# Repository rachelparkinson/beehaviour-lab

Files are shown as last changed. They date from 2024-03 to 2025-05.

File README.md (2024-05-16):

# Beehaviour Lab Project

## Description
This is the project file for the Beehaviour Lab

## Contents
aparatus_templates --> dxf files for laser cutting the Beehaviour Lab stand and cages

rPi_program --> Raspberry Pi program for controlling Beehaviour Lab and recording data

vid_audio_processing --> code for adjusting frame rate of video and combining video and audio files

database --> code for scraping experiment data from .json metadata files and filing in MongoDB

## Contributors
All design & code written by Rachel Parkinson, laser cutting files produced by Jennifer Scott.

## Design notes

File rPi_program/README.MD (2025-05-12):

# Beehaviour Lab Raspberry Pi Program

## Description
Program to control rPi and components of Beehaviour Lab. 

## Installation
All files can be transferred to an rPi Model 4B to control: rPi NoIR camera (V2), Røde SmartLav+ lapel microphone, DHT22 temperature and humidity probe, LED lighting panels, time clapper (buzzer + LEDs), and OLED display screen.

## Usage
Update config.json with experiment-specific information, including recording segment length and number of replicates.

Run program from "main.py" file. 

## Requirements

Use a setup rPi to download all requirements, and then transfer to the other rPis using VNC. 

## 1. on the Internet-connected rPi:

```
#!/bin/bash

# Create directories
mkdir -p rpi_packages/apt
mkdir -p rpi_packages/pip

# Download apt packages and dependencies
cd rpi_packages/apt
apt-get download \
    python3-opencv \
    opencv-data \
    ffmpeg \
    i2c-tools \
    python3-smbus \
    alsa-utils \
    $(apt-cache depends python3-opencv opencv-data ffmpeg i2c-tools python3-smbus alsa-utils | grep -E 'Depends|Recommends|Suggests' | cut -d: -f2 | tr -d '<>' | sed '/^$/d')

# Download pip packages
cd ../pip
pip3 download \
    opencv-python \
    picamera2 \
    tflite-runtime \
    adafruit-circuitpython-ssd1306 \
    RPi.GPIO \
    board \
    busio \
    adafruit-blinka

# Create tar archive
cd ../..
tar -czvf rpi_packages.tar.gz rpi_packages/
```

## 2. on the other rPis:

```
#!/bin/bash

# Extract the archive
tar -xzvf rpi_packages.tar.gz

# Install apt packages
cd rpi_packages/apt
sudo dpkg -i *.deb

# Handle any dependency issues
sudo apt --fix-broken install

# Install pip packages
cd ../pip
pip3 install --no-index --find-links . *.whl
```

## 3. enable I2C on each rPi for the OLED display

```
sudo raspi-config
# Navigate to Interfacing Options > I2C > Enable
```

## 4. For audio recording, set the USB mic as the default audio input

```
sudo nano /etc/asound.conf
# Add the following lines to the file:
   pcm.!default {
       type plug
       slave.pcm "plughw:1,0"  # Adjust card,device numbers as needed
   }
```

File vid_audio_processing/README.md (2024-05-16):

# Video and audio file procesing

## Description
Programme for adjusting the frame duration on videos and aligning with audio recordings plus offset. 

## Files
resample_framerate.py --> recalculates the framerate of the video file knowing the number of frames (taken from the video_metadata file) and expected duration (5 minutes).

combine_vid_aud.py --> merge the separate audio and video files.

clip_media.py --> quick script to trim  files (i.e., extract segment from video)

## To do:
Need to check: is number of frames accurately represented in video_metadata.json files? If so, use this instead of querying as it takes forever.

Also: how accurate is the 0.01s time offset?

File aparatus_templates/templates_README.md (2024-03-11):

# Template files

Files are for laser cutting the Beehaviour Lab stand and cages. Stand printed in 5 mm perspex, and boxes may be printed in 3 or 5 mm clear perspex.

# Assembly

Stands are assembled with the use of M3 screws. Cages are assembled using Tensol acrylic glue. Components are affixed to stands using M2 screws.

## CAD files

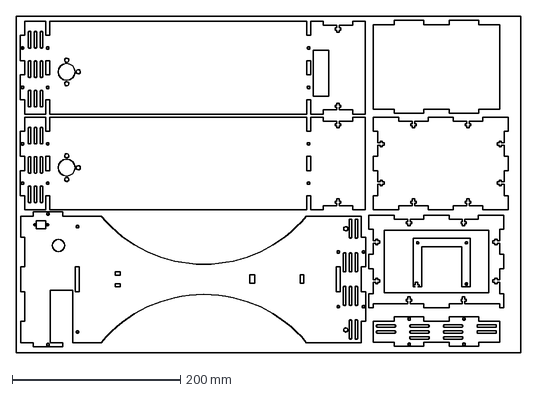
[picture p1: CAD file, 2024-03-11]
aparatus_templates/White_Bulk_Sheet1.dxf
600.0 x 400.0 mm

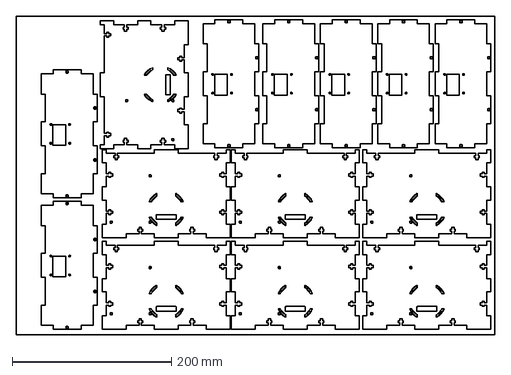
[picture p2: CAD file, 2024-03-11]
aparatus_templates/White_Bulk_Sheet2.dxf
600.0 x 400.0 mm

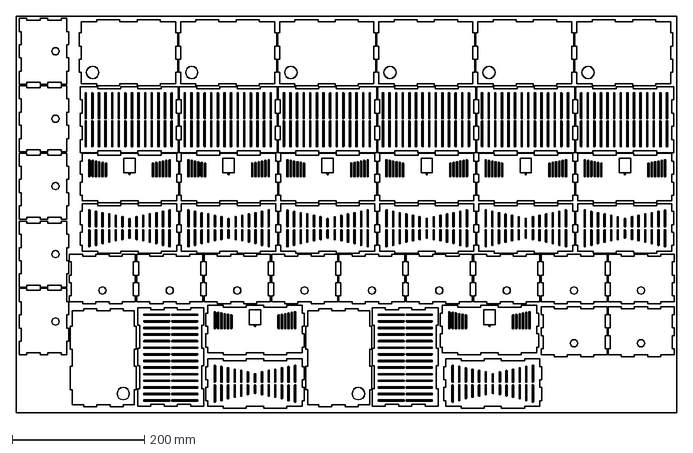
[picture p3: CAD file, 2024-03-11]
aparatus_templates/3mmBox.dxf
1000.0 x 600.0 mm

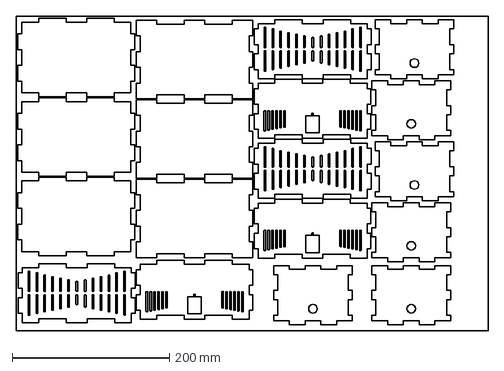
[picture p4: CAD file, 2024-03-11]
aparatus_templates/5mmBox.dxf
600.0 x 400.0 mm

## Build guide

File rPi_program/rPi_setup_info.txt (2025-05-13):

## NEW VERSION - rPi SETUP for BEEhaviour Lab ##

## ---------------------- ##

Start with:
- SD card (using 128 GB)
- Raspberry Pi 4B (4 GB)
- USB-SATA cable
- PiCam (using NoIR V2)
- SSD (Gigastone Game Pro SSD 512 GB)

## ---------------------- ##

1. Flash card
- Download / open Raspberry Pi Imager (at least v1.7)
- Select Raspbian version:
  - Old setup uses DEBIAN-BULLSEYE (newest release isn't working with VNC as of 14/10/2023)
  - New setup uses DEBIAN-BOOKWORM 12
- Select SD card from storage option
- Click “Settings” and enable:
  - Enable SSH
  - Set username and password (e.g., username: rPi1, password: pipass)

## ---------------------- ##

2. Connect to monitor, mouse, keyboard
- Make sure Pi is powered off before inserting SD card
- Insert SD, plug it in

## ---------------------- ##

4. rPi configuration

# Download setup file from GitHub:
wget https://github.com/rachelparkinson/beehaviour-lab/archive/refs/heads/main.zip

# Unzip and run:
unzip main.zip
cd beehaviour-lab-main/rPi_program
chmod +x setup_rpi.sh
./setup_rpi.sh

## ---------------------- ##

5. Log in to RealVNC to allow for file transfer
sudo vnclicensewiz

## ---------------------- ##

6. Transfer git program (from local copy via ssh)

# Fix rPi name (e.g., rPi1...) and replace <raspberry_pi_ip> with actual IP. 
# Need to be on same wifi network as rPi for this to work

scp -r /Users/user/Documents/beehaviour-lab/rPi_program rPi21@<raspberry_pi_ip>:/home/rPi21/

## ----------------------- ## 

8. Setup SSD

Connect SSD
- Connect to USB 3.0 (blue)
- wait 30s, then in Gparted select ‘GParted > Refresh Devices’ (1-2 mins)
- Select SSD (from drop-down menu at top right) and wait for the information to display

Create Partition Table
- Select ‘Device > Create Partition Table’ from top menu
- Keep default settings, select ‘Apply’ (wait a few mins, might not look like anything’s happening)

Create Partition
- select ‘Partiton > New’ from top menu
- Keep all default settings (including the ext4 filesystem), but add a sensible Label to help identify it later on (e.g., ‘WDSSD’)
- Select ‘Edit > Apply All Operations’ from the top menu and click yes to the warning once you’ve checked everything (may take some time)

Run ssd_setup.py

cd ~/rPi_program
chmod +x ssd_setup.sh    # (only needed once to make it executable)
./ssd_setup.sh

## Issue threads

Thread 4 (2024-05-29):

Implement automation for post-processing steps

OllyK, 2024-05-29:
More automation is needed to perform post-processing steps, i.e.:
- organise files
- fix video frame rates
- insert data into DB

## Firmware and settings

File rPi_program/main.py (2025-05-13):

import time
import threading
import queue
import busio
import board
import RPi.GPIO as GPIO
import os
import adafruit_ssd1306
import json
from picamera2 import Picamera2

from load_config import load_config

from threads.LED_panels import lights
from threads.OLED_display import OLED_wipe
#from threads.temp_rh import DHT
from threads.pi_cam import record_video, convert_h264_to_mp4
from threads.USB_mic import find_usb_mic, record_audio, convert_wav_to_flac
#from threads.time_clapper import time_clapper
from rPi_program.threads.video_inference_ncnn import run_ncnn_inference

# main file for the rPi beehaviour box. 
# Setup duration of recordings directly from this file.

if __name__ == "__main__":
    
    # Load the configuration for this Raspberry Pi
    config = load_config()
    
    ####################
    ## METADATA INPUT ##
    ####################
    day = config["day"] # Date (YEARMONTHDAY e.g., 240131)
    ID = config["ID"]
    Rec_time = config["Rec_time"] #recording segment time (s)
    reps = config["reps"] #how many recordings in loop
    spaces = config["spaces"] #space between end of one recording and beginning of next (s)
    
    ################################################################
    ## don't change this:
    Name = config["Name"]
    rPi_num = config["rPi_num"]
    start_time = time.time() #get start time
    ssd_path = config["ssd_path"] # Name folder on SSD to save files
    #################################################################
    

    
    #day_folder = os.path.join(ssd_path, day)
    
    def create_incremental_subfolder(base_folder):
        subfolders = [f for f in os.listdir(base_folder) if os.path.isdir(os.path.join(base_folder, f))]
        
        if not subfolders:
            new_subfolder = "001"
        else:
            last_subfolder = max(subfolders, key=lambda x: int(x))
            new_subfolder = f"{int(last_subfolder) + 1:03d}"
        
        subfolder_path = os.path.join(base_folder, new_subfolder)
        os.makedirs(subfolder_path)
        return subfolder_path
    
    if not os.path.exists(os.path.join(ssd_path, day + '-' + ID)):
        os.makedirs(os.path.join(ssd_path, day + '-' + ID))
        
    
    # Check USB mic card & device
    card, device = find_usb_mic()
    print(f"Found USB microphone on card {card}, device {device}")
    
    ###############################
    ## Loop to repeat threads ##
    ############################
    
    for replicate in range(1, reps + 1):
        
        seg_time = time.time()
        
        day_folder = create_incremental_subfolder(os.path.join(ssd_path, day + '-' + ID))
        
        # Define metadata for .json file
        metadata = {
            "treatment": config["treatment"],
            "ID": config["ID"],
            "test compound": config["test compound"],
            "concentration": config["concentration"],
            "unit": config["unit"],
            "background solution": config["background solution"],
            "background solution conc (M)": config["background solution conc (M)"],
            "pollen Y/N": config["pollen Y/N"],
            "species": config["species"],
            "group": config["group"],
            "experimenter": config["experimenter"],
            "day": config["day"],
            "segment length": Rec_time,
            "number segments": reps,
            "time between segments": spaces,
            "rPi_name": Name,
            "rPi start time": start_time,
            "current segment start time": seg_time,
            "current segment number": replicate,
            "Additional description": config["Additional description"],
            "Video framerate": config["framerate"],
            "Video resolution": config["resolution"],
            "Video encoder": config["video encoder"],
            "Mic sample rate": config["mic sample rate"],
            "Audio recording settings": config["audio recording settings"],
            "Video conversion settings": config["video conversion settings"],
            "Audio conversion settings": config["audio conversion settings"]
        }
    
        metadata_name = os.path.join(day_folder, day + '_' + Name + '_' + str(replicate) + '_' + ID + '_metadata.json')
    
        with open(metadata_name, 'w') as file:
            json.dump(metadata, file, indent=4)
        
        GPIO.cleanup()
    
        #LED panels
        R_LED_PIN = config["R_LED_PIN"]
        W_LED_PIN = config["W_LED_PIN"]
        
        # LED and Buzzer
        BUZZER_PIN = config["BUZZER_PIN"]
        LED_PIN = config["LED_PIN"]
        
        #OLED display & MEMs
        i2c = busio.I2C(board.SCL, board.SDA)
        
        #pi cam
        resolution = tuple(config["resolution"]) #max res with high framerate
        framerate = config["framerate"] 
        
        #create thread-safe queue
        data_queue = queue.Queue()
        
       #Wipe the OLED screen
        GPIO.setmode(GPIO.BCM)
        display = adafruit_ssd1306.SSD1306_I2C(128, 32, i2c)
        display.fill(0)
        
        OLED_wipe(Name, data_queue, i2c)
        
        # Filenames (as per day_folder)
        #buzz_file = os.path.join(day_folder, day + '_' + Name + '_' + str(replicate) + '_' + ID + '_buzz.json')
        #DHT_file = os.path.join(day_folder, day + '_' + Name + '_' + str(replicate) + '_' + ID + '_DHT.json')
        audio_file = os.path.join(day_folder, day + '_' + Name + '_' + str(replicate) + '_' + ID + '_audio.wav')
        video_file = os.path.join(day_folder, day + '_' + Name + '_' + str(replicate) + '_' + ID + '_video.h264')

        #Initialize camera:
        picam2 = Picamera2()
        
        #Create threads for each task, pass relevant parameters
        lights_thread = threading.Thread(target=lights, args=(R_LED_PIN, W_LED_PIN, Rec_time))
        #DHT_thread = threading.Thread(target=DHT, args=(DHT_file, data_queue, start_time, seg_time, Rec_time))
        USB_mic_thread = threading.Thread(target=record_audio, args=(Rec_time, audio_file, card, device))
        cam_thread = threading.Thread(target=record_video, args=(picam2, framerate, resolution, video_file, Rec_time))
        #time_clapper_thread = threading.Thread(target=time_clapper, args=(rPi_num, BUZZER_PIN, LED_PIN, Rec_time, buzz_file))
        
        #Start threads
        lights_thread.start()
        #DHT_thread.start()
        cam_thread.start()
        USB_mic_thread.start()
        #time_clapper_thread.start()
        
        # Wait for Rec_time
        time.sleep(Rec_time)
        
        #start a timer
        time1 = time.time()
        
        # join threads
        print("Joining threads...")
        
        #Wait for all threads to complete
        lights_thread.join()
        #DHT_thread.join()
        cam_thread.join()
        USB_mic_thread.join()
        #time_clapper_thread.join()

        #Check to be sure camera is closed
        picam2.close()
        
        print("Threads joined, starting compression & conversion of video & audio files")
        
        print("Video file is:")
        print(video_file)
        
        h264_video_file = str(video_file)
        wav_file = str(audio_file)

        convert_h264_to_mp4(h264_video_file)
        convert_wav_to_flac(wav_file)
        
        print("Compression & conversion complete.")

        # Add YOLO inference after video conversion
        mp4_video_file = h264_video_file.replace('.h264', '.mp4')
        yolo_thread = threading.Thread(target=run_tflite_inference, 
                                    args=(mp4_video_file, day_folder, day, Name, replicate, ID))
        yolo_thread.start()
        yolo_thread.join()  # Wait for YOLO inference to complete

        print("YOLO inference complete.")
        
        time2 = time.time()
        runover_time = time2-time1
        print("Elapsed processing time: ", runover_time)
        
        if replicate < reps:
            # Check to see whether there is any time left on counter:
            if runover_time < spaces:
                time.sleep(spaces - runover_time)
            else:
                time.sleep(1) #if not, just get on with next recording

#clean up pins
GPIO.cleanup()

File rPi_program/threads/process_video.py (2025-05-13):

from pathlib import Path
from typing import Optional, List, Dict, Tuple
import click
import polars as pl
import numpy as np
from scipy.optimize import linear_sum_assignment
import matplotlib as mpl

mpl.use("Agg")
import matplotlib.pyplot as plt
from object_detection.yolo_predict_to_file import save_bboxes_to_file

MODEL_PATH = Path("best.pt")
CONF_THRESHOLD = 0.0
XYWH = True
TRACK = True
FILTER_LABEL = 0
NUM_OBJECTS = 5
CSV1_NAME = "yolo_tracking_raw.csv"
CSV2_NAME = "yolo_tracking_velocity.csv"
CSV3_NAME = "yolo_tracking_velocity_fixed_ids.csv"


def extract_flow_info(df: pl.DataFrame, label: int) -> pl.DataFrame:
    """
    Extracts flow information from the DataFrame.

    Args:
        df (pl.DataFrame): The DataFrame containing bounding box data.
        label (int): The label to filter on.

    Returns:
        pl.DataFrame: The DataFrame with flow information, including velocity and speed.
    """
    # Filter on label
    df = df.filter(pl.col("class_id") == label)
    # If the file contains cols x1, y1, x2, y2, convert to x, y, w, h
    if "x1" in df.columns:
        df = df.with_columns(
            [
                (pl.col("x2") - pl.col("x1")).alias("w"),
                (pl.col("y2") - pl.col("y1")).alias("h"),
                # x and y are the centre of the bounding box
                (pl.col("x1") + pl.col("w") / 2).alias("x"),
                (pl.col("y1") + pl.col("h") / 2).alias("y"),
            ]
        )

    df = df.sort(["track_id", "frame_id"])

    df = df.with_columns(
        [
            (pl.col("x") - pl.col("x").shift(1)).over(["track_id"]).alias("dx"),
            (pl.col("y") - pl.col("y").shift(1)).over(["track_id"]).alias("dy"),
        ]
    )
    df = df.with_columns(
        [(pl.col("dx").pow(2) + pl.col("dy").pow(2)).sqrt().alias("speed")]
    )

    # Handle nulls
    df = df.fill_null(0)

    return df


def fix_ids(df: pl.DataFrame) -> pl.DataFrame:
    """
    Fixes the IDs in the DataFrame by assigning stable IDs to objects across frames.

    Args:
        df (pl.DataFrame): The DataFrame containing bounding box data.

    Returns:
        pl.DataFrame: The DataFrame with fixed stable IDs.
    """
    df = df.sort(["frame_id"])

    # List to store final rows (dicts)
    stable_rows: List[Dict[str, Optional[float]]] = []
    stable_id_list: List[int] = list(range(1, NUM_OBJECTS + 1))
    # Dictionary to store last known positions of stable IDs
    stable_positions: Dict[int, Optional[Tuple[float, float]]] = {
        sid: None for sid in stable_id_list
    }

    # Add "stable_id" column
    all_columns: List[str] = df.columns
    if "stable_id" not in all_columns:
        all_columns += ["stable_id"]

    # Create a list of unique frame IDs to iterate over
    frames_list: List[int] = (
        df.select(pl.col("frame_id")).unique().sort("frame_id").to_series().to_list()
    )

    for f in frames_list:
        subdf: pl.DataFrame = df.filter(pl.col("frame_id") == f)

        x_vals: np.ndarray = subdf["x"].to_numpy()
        y_vals: np.ndarray = subdf["y"].to_numpy()
        this_frame_count: int = len(x_vals)

        # Build cost matrix: shape=(num_objects, this_frame_count)
        cost: np.ndarray = np.zeros((NUM_OBJECTS, this_frame_count), dtype=np.float32)

        # Fill cost = distance from each stable ID to each detection
        for i_row, sid in enumerate(stable_id_list):
            old_pos: Optional[Tuple[float, float]] = stable_positions[sid]
            if old_pos is None:
                # Never matched this sid, put large distance to discourage matching
                old_x, old_y = 1e9, 1e9
            else:
                old_x, old_y = old_pos

            for j_col in range(this_frame_count):
                dx: float = x_vals[j_col] - old_x
                dy: float = y_vals[j_col] - old_y
                cost[i_row, j_col] = np.sqrt(dx * dx + dy * dy)

        # Hungarian assignment if detections exist
        if this_frame_count > 0:
            row_idx, col_idx = linear_sum_assignment(cost)
            # row_idx, col_idx each has length = min(num_objects, this_frame_count)
        else:
            row_idx, col_idx = [], []

        matched_sids: set[int] = set()
        matched_detections: set[int] = set()

        # Assign matched pairs
        for i_row, j_col in zip(row_idx, col_idx):
            sid: int = stable_id_list[i_row]
            matched_sids.add(sid)
            matched_detections.add(j_col)

            new_x: float = x_vals[j_col]
            new_y: float = y_vals[j_col]
            # Update stable position
            stable_positions[sid] = (new_x, new_y)

            # Build the row from subdf
            row_data: Dict[str, Optional[float]] = subdf.slice(j_col, 1).to_dicts()[0]
            row_data["stable_id"] = sid
            stable_rows.append(row_data)

        # Handle unmatched stable IDs => insert a blank row
        unmatched_sids: set[int] = set(stable_id_list) - matched_sids
        for sid in unmatched_sids:
            # Produce exactly 1 row for this stable ID with 'None' for columns
            blank_row: Dict[str, Optional[float]] = {col: None for col in all_columns}
            blank_row["frame_id"] = f
            blank_row["stable_id"] = sid

            # Carry forward last known positions:
            old_pos = stable_positions[sid]
            if old_pos is not None:
                blank_row["x"] = old_pos[0]
                blank_row["y"] = old_pos[1]

            stable_rows.append(blank_row)

    # Build final dataframe from the list of dicts
    df_out: pl.DataFrame = pl.DataFrame(stable_rows)
    df_out = df_out.sort(["frame_id", "stable_id"])
    return df_out
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

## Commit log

2023-08-07 moved temp_rh.py to sensors folder
2023-08-07 added control/OLED_button.py code for OLED screen and push button
2023-08-07 LED_panels.py file added
2023-08-07 pin updated OLED_display.py
2023-08-07 LED_panel function put within while statement
2023-08-09 GPIO.BCM line commented out on LED_panels.py
2023-08-09 fixed naming issue Audio_file --> audio_file
    [main.py]
2023-08-09 restructured file system, debugged LED_panels.py
2023-08-09 updated temp_rh.py and main.py threads, debugged in rPi
2023-08-09 main debugged with OLED, temp_rh and LEDs
2023-09-26 Added file to control buzzer and LED for synchronization of video and audio
2023-09-26 main updated with buzzer thread
    [main.py]
2023-09-28 button_wait.py added to start recording with initial button push, main.py updated to integrate
2023-10-02 Buzzer and LED decoupled, solved hum issue
    [main.py]
2023-10-02 camera debugged to close properly at end of recording
2023-10-03 before running programme, kill all camera access (fixes issue of camera being inaccessible).
    [main.py]
2023-10-03 Video frames labeled with time
2023-10-03 pi_cam now updates frame times to JSON
2023-10-03 class for MCP3008 ADC
2024-01-30 updates and changes throughtout, including new time_clapper.py file for buzzer/LED
    [LED_panels.py, OLED_display.py, USB_mic.py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]
2024-01-30 removed old .py threads
2024-02-02 removed old function for activating buzzer/LED
2024-02-02 split conversion/compression steps into separate threads for video and audio
2024-02-02 find_usb_mic function moved to USB_mic.py thread
2024-03-11 Added template files for laser cutting
    [3mmBox.dxf, 5mmBox.dxf, White_Bulk_Sheet1.dxf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]
2024-06-18 addressed errors on main.py and config files
    [main.py]
2024-07-26 Adds prototype script for data transfer
2025-05-12 added YOLOv11 model NCNN version
    [model.ncnn.param]
